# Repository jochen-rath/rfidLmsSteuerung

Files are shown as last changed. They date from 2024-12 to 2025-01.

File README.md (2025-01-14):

# Den Lyrion Media Server mit RFID Karten steuern

## Inhalt

* [Vorbemerkung](#vorbemerkung)
* [Aufbau](#aufbau)
* [Beispiel](#beispiel)
* [RFID Steuerung auf ESP32-Display](#rfidsteuerung)
* [RFID Karten Zuordnen](#rfidkartenzuordnen)
* [Installation restlicher Komponenten](#installationkomponenten)
* [ESP32-S3 Firmware selber erstellen](#esp32s3firmwareerstellen)

<a name="vorbemerkung"/>

## Vorbemerkung

Logitech hat vor lange Zeit einen kostenlosen Mediaserver bereit gestellt, mit dem man kostenlos seine Musik im ganzen Haus verteilen kann. Den Logitech (bzw. Lyrion) Media Server oder kurz LMS. Man braucht einen Rechner, der als Server arbeit und die Musik an verschiedene Clienten schickt. Diese können Rechner, Raspberry Pis, Handys oder seit kurzen ESP32 sein. Gerade die ESP32 sind eine sehr günstige alternative, die Musik zu empfangen.

Den LMS kann man gut mit Handy und Browser fernsteuern. Doch habe ich nicht immer mein Handy dabei und möchte auch gerne, dass meine Kinder selbständig Lieder und Hörbücher starten können. Für letzteres gibt es auch gute eigenständige Systeme, wie z.B. der TonUINO, aber gerade für ältere Kinder ist dies irgendwann nicht mehr zeitgemäß. Da ich selber schon länger den Lyrion Media Server (LMS) nutze und meinen Kinder den irgendwann auch in deren Zimmer einbauen wollte, entschied ich mich, mir eine RFID - Steuerung für diesen einzurichten.

<a name="aufbau"/>

## Aufbau

Aus folgenden vier Komponenten besteht ein komplettes System

1. Server mit einer laufenden LMS Instanz. ([Ich nutze Docker](https://hub.docker.com/r/lmscommunity/lyrionmusicserver))
2. Einen Clienten, der die Musik wiedergibt. ([Ich nutze squeezelite-esp32](https://github.com/sle118/squeezelite-esp32))
3. Die hier vorgestellte RFID-Steuerung.
4. Ein Pythonskript, welches den IDs der RFID-Karten einer Aktion zuordnen.

<a name="beispiel"/>

## Beispiel

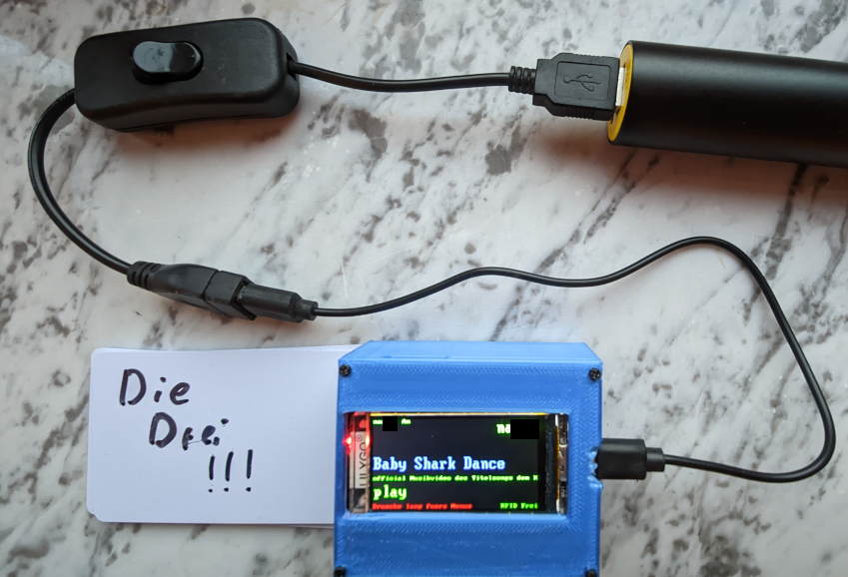
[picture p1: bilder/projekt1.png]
Beispiel 1

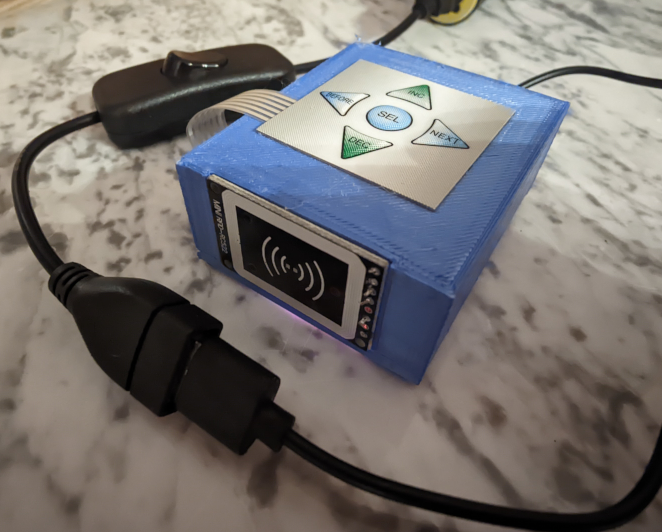
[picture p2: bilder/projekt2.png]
Beispiel 2


<a name="rfidsteuerung"/>

## RFID Steuerung auf ESP32-Display

### Komponenten
* T-Display-S3 ESP32 S3 with 1.9 inch ST7789 LCD Display
* MFRC-522 Mini RC522
* Key Button Membrane Switch 3 ([Color: 5key-matrix-keyboard](https://www.aliexpress.com/item/1005004528531101.html))
* USB Schalter
* USB Powerbank
* Gehäuse aus dem 3D-Druck

### Firmware flashen
```
pip install esptool
esptool.py --chip esp32s3 --port /dev/ttyACM0 erase_flash
esptool.py --chip esp32s3 --port /dev/ttyACM0 write_flash -z 0 esp32-S3_display_firmware.bin
```

### LMS-Steuerung aufs Display laden
Zur Übertragung des Skripts auf das ESP32 Display benutze ich Thonny. Wähle Run --> Select Interpreter --> Micropython (ESP32) und suche dann den richtigen Port. Speicher damit *squeezeplayerSteuerung.py* als *main.py* auf dem Display.

Wähle zuerst den Interpreter:

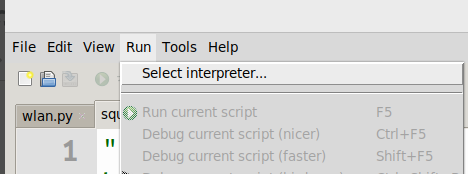
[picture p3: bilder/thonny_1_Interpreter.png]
Interpreter


Nimm MicroPython (ESP32) und den passenden Port:

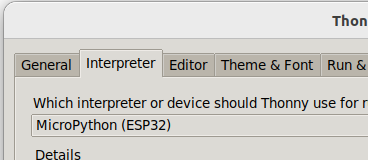
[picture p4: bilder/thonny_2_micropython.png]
Micropython


Drücke auf Save Copy und wähle das Micropython Device:

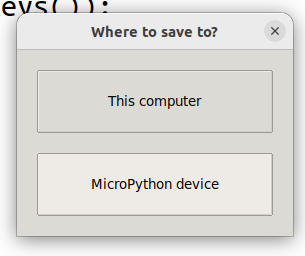
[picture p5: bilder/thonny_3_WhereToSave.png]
WhereToSave


### LMS-Steuerung anpassen
Rufe das Skript *paramter.py* in Thonny auf und passe folgende Angaben an:

* wlanname
* wlanpasswort
* squeezeclient
* lmsserverip
* rfidserverip

Speicher dann *parameter.py* auf dem Display.

### Komponenten Verbinden
**RFID**

| ESP32-S3 Display | MFRC-522 Mini RC522|
| --- | --- |
| V3.3 | V3.3 |
| GND | GND |
|  1 | MISO|
|  2 | MOSI |
|  3 | SCK|
| 10 | SDA|

**5 Button Switch**

| ESP32-S3 Display | 5 Button Switch|  Beschriftung |
| --- | --- | --- |
| GND | 1  | |
|  43 | 2  |SEL |
|  44 | 3  |DEC |
|  18 | 4  |INC |
| 17  | 5  |BEFORE |
| 21  | 6  |NEXT|

Ich habe den 5er Taster direkt an das ESP32 gelötet, um Platz zu sparen. Nicht gesteckt. Dazu habe ich den Stecker abgeschnitten und das die Enden der Kabel direkt an die Pins gelötet. Dadurch muss das Gehäuse nicht so hoch sein.

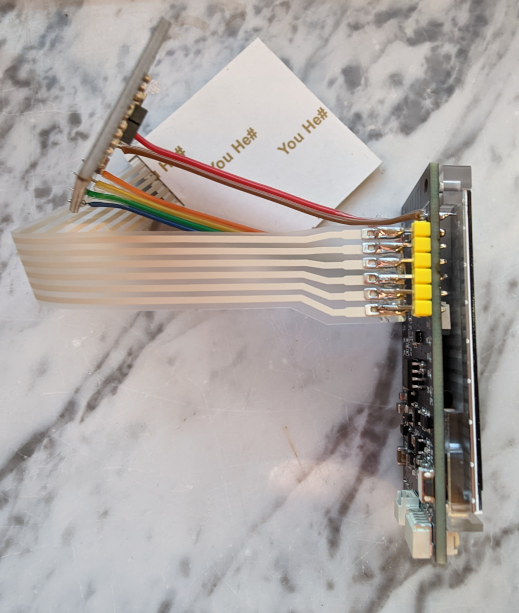
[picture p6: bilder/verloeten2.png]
verloeten 2
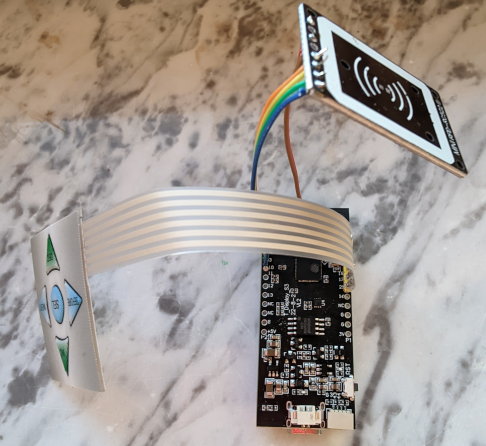
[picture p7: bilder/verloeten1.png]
verloeten 1
  

Da das Display die Schrauben verdeckt, klebe ich die Steuerung mit Heißkleber in das Gehäuse:

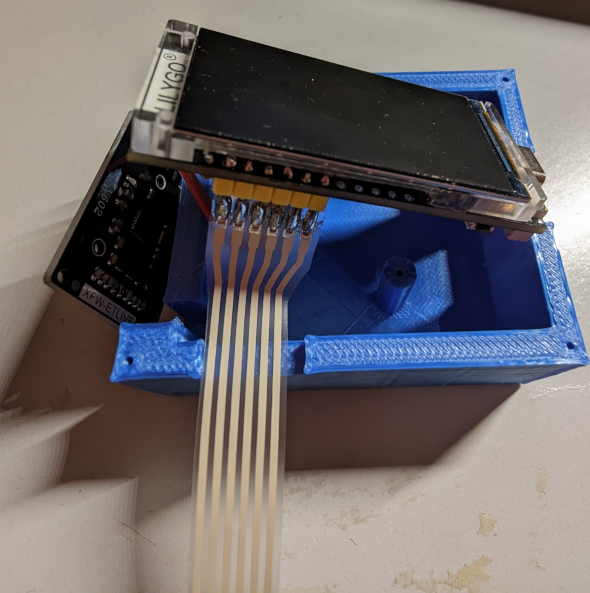
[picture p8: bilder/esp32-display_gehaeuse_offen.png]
Gehaeuse offen
 

<a name="rfidkartenzuordnen"/>

## RFID Karten Zuordnen

Die RFID Karten werden mit Hilfe eines Python Skripts verschiednenen Musikordnern, -dateien, -streams, Hörbüchern oder An- Ausschaltern zugeordnet.

1. Kopiere das Skript *httpServerGetPost.py* und die Datei *rfidKarten.csv* auf einen Server in den Ordner */home/pi/rfidLMS*
2. Kopiere als admin die Datei *rfidLMS.service* nach */lib/systemd/system*:  *sudo cp  rfidLMS.service /lib/systemd/system/*
3. Aktiviere das Skript als Service mit folgenden Befehlen:

```
sudo systemctl enable rfidLMS
sudo systemctl daemon-reload
sudo systemctl start rfidLMS
```
Möchtest du andere Pfade verwenden, passe die Ordner in den Skripten an. Ich habe die Datei *rfidKarten.csv* in einem Pfad gespeichert, auf dem ich per Samba mit meinem Handy zugriff habe. So kann ich einfach neue Karten in diese Datei einpflegen, indem ich mit dem NCF Reader meines Handy die Karten-ID auslese und diese einer Aktion zuordne.

<a name="installationkomponenten"/>

## Installation restlicher Komponenten

### LMS Server

Zur Docker-Installation [kopiere dir die Docker-Compose Datei](https://hub.docker.com/r/lmscommunity/lyrionmusicserver) auf deinen Server und starte den LMS Server mit 
```
docker-compose up -d
```
Richte den Server den eigenen Anforderungen entsprechend ein.

### squeezelite-esp32

#### Offiziele Clienten

Es gibt verschiedene Projekte, die direkt das Squeezelite-ESP32 unterstützen. Diese finden sich hier:

[Firmware for ESP Audio Dock](https://sonocotta.github.io/esp32-audio-dock/)

#### ESP32-S3

Aus Kostengründen nutze ich aber den ESP32-S3, welcher keine offiziele Unterstützung besitzt. Für den ESP32-S3 Clienten braucht man folgende Teile:

1. ESP32-S3 Development Board (z.B. von Aliexpress, auf 16MB achten: N16R8 - 8M psram, 16M flash)
2. DAC Module 1334 UDA1334A I2S DAC (z.B. von Aliexpress)
3. SONOFF Basic R2 (Zum An-Aus Schalten mitteils RFID-Karten)
4. USB Netzteil
5. USB Splitter, Eins auf Zwei (Nur ein Netzteil für Boxen und Esp32)
6. USB Boxen
7. 3.5mm Audio Aux Cable Anti-interference Ground Loop Noise Filter (Falls der Sound störgeräusche enthält. Dies kann bei mir vorkommen, wenn Boxen und ESP32-S3 am gleichen Netzteil hängen.)

#### ESP32-S3 Installation

**Softwareinstallation**

Für die 16 MB esp32-s3
```
pip install esptool
esptool.py --chip esp32s3 --port /dev/ttyACM0 erase_flash
esptool.py -p /dev/ttyACM0  -b 460800 --before default_reset --after hard_reset --chip esp32s3  write_flash --flash_mode dio --flash_size detect --flash_freq 80m 0x0 esp32s3_16MB_squeeze_bootloader.bin 0x8000 esp32s3_16MB_squeeze_partition-table.bin 0xd000 esp32s3_16MB_squeeze_ota_data_initial.bin 0x10000 esp32s3_16MB_squeeze_recovery.bin 0x150000 esp32s3_16MB_squeeze_squeezelite.bin

```

**ESP32-S3 mit DAC verbinden**

Verlöte folgende Punkte zwischen dem ESP und dem DAC

| ESP32-S3 | DAC 1334|
| --- | --- |
| V3.3 | V3.3 |
| GND | GND |
|  42 | WSEL |
|  41 | DIN |
|  40 | BCLK

Mache die Verbindung nicht zu kurz, sonst erzeugt der WLAN des esp32-S3 Störungen bei der Musikwiedergabe. 

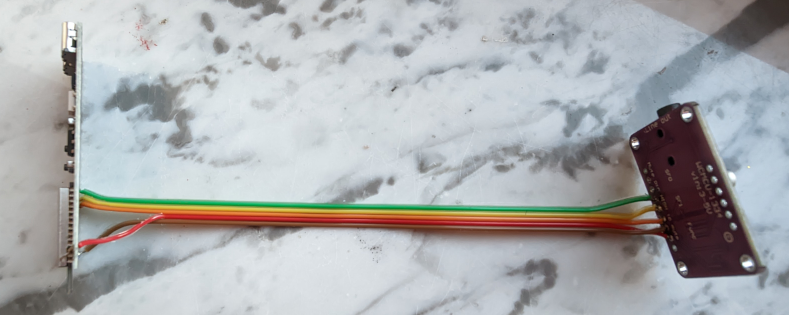
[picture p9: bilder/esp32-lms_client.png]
Verbindung


**ESP32-S3 Einrichten**

Verbinde dich mit dem ESP32-S3 mit dem Handy, WLAN squeezelite-esp32, Passwort squeezelite. Richte dein Wlan ein und merk dir die IP-Adresse, mit der sich der Squeezelite mit deinem Heimnetz verbindet. Rufe nach dem Neustart diese IP-Adresse auf.

Richte unter Audio den Playername und den LMS-Server ein:

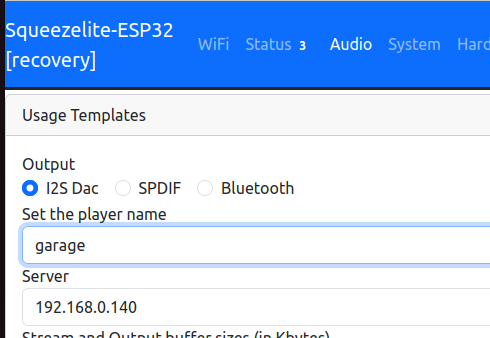
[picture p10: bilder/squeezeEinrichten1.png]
PlayerName


Richte unter Hardware den DAC entsprechend obiger Tabelle ein, bzw. deiner eigenen Verlötung:

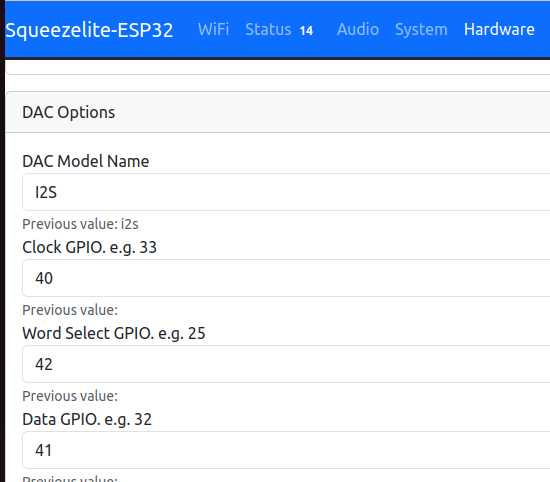
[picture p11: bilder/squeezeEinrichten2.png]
DAC


**Autoconnect**

Die hier genuzte Version des esp32-squeezelite Players kann sich nicht selber mit dem Server verbinden. [Hier wird beschrieben, welcher Schritt nochfehlt](https://github.com/sle118/squeezelite-esp32/issues/411#issuecomment-2104861151)

Es muss noch autoexec 1 im NVS-Editor eingefügt werden:

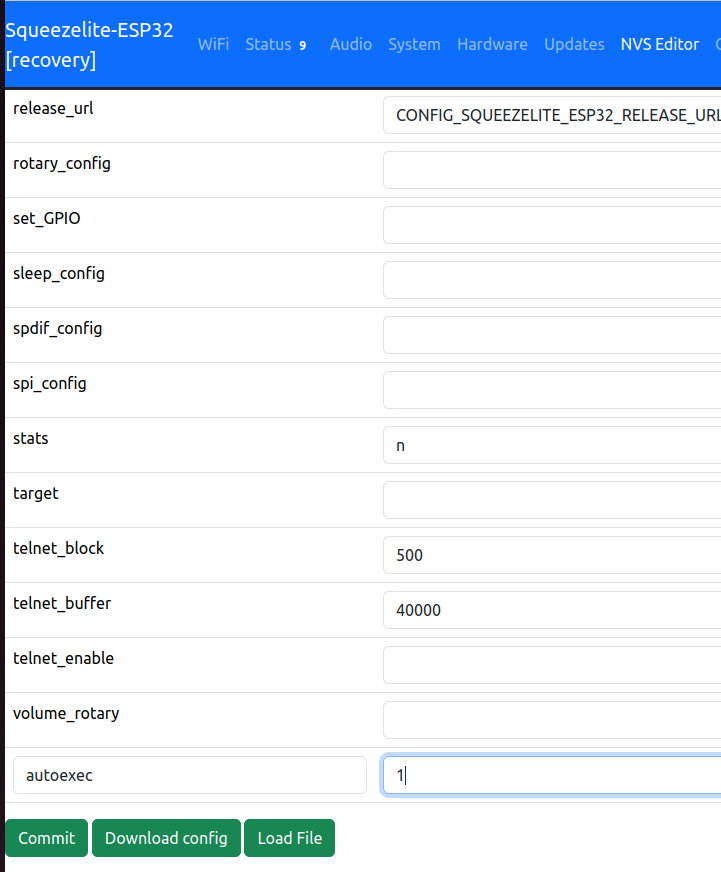
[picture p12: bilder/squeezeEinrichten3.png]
autoexec


Nach dem Neustart muss dies so aussehen:

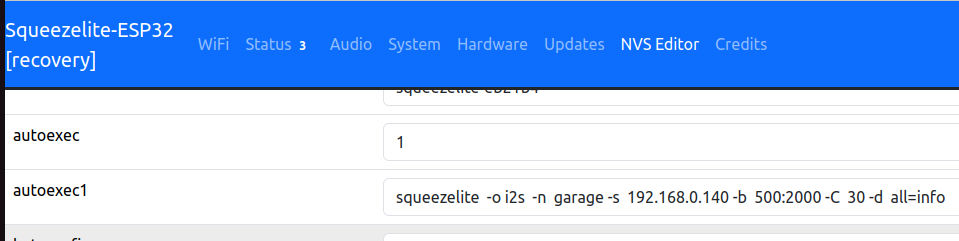
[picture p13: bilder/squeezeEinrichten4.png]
Ergebnis


### Sonoff Basic einrichten

Zum An und Auschalten der ESP32-S3 Clienten nutze ich den Sonoff Basic R2, welcher [mit einer Tasmota Firmaware geflasht wurde.](https://tasmota.github.io/docs/devices/Sonoff-Basic/)

**Sonoff Flashen**

Ablauf:

1. [Lade dir die Firmware herunter](https://ota.tasmota.com/tasmota/release/tasmota-DE.bin)
2. Öffne das Gehäuse
3. Löte 5 Pins an die richtige Stelle.
4. Verbinde die 5 Pins mit einem FT232RL USB-Serial Adapter, halte dabei den Reset-Knopf gedrückt.
5. Lösche den Speicher und flashe die Tasmota mit folgenden Befehlen:

```
esptool.py --port /dev/ttyUSB0 erase_flash
esptool.py --port /dev/ttyUSB0 write_flash -fs 1MB -fm dout 0x0 tasmota-DE.bin
```
[Hier ist eine ausführliche Anleitung mit Bildern.](https://medium.com/@jordanrounds/sonoff-basic-r2-tasmota-aa6f9d4e033f)

<a name="esp32s3firmwareerstellen"/>

## ESP32-S3 Firmware selber erstellen

Sollte dein ESP32-S3 nicht zu den hier vorgestellten Konfigurationen passen, erstelle deine eigene Firmware mit folgenden Befehlen:

```
mkdir ~/esp
cd ~/esp
git clone -b v4.4.4 --recursive https://github.com/espressif/esp-idf.git esp-idf-v4.4
~/esp/esp-idf-v4.4/install.sh
. ~/esp/esp-idf-v4.4/export.sh
git clone --recursive https://github.com/sle118/squeezelite-esp32.git
cd squeezelite-esp32
cp build-scripts/I2S-4MFlash-sdkconfig.defaults sdkconfig.defaults

```

Änder nun in der Datei sdkconfig.defaults die *CONFIG_IDF_TARGET="esp32"* zu *CONFIG_IDF_TARGET="esp32s3"*

**ESP32-S3 Konfigurieren**

Passe mit dem Befehl *idf.py menuconfig* folgende Einstellungen an. Da der ESP32-S3 kein Bluetooth hat, muss dies deaktiviert werden.

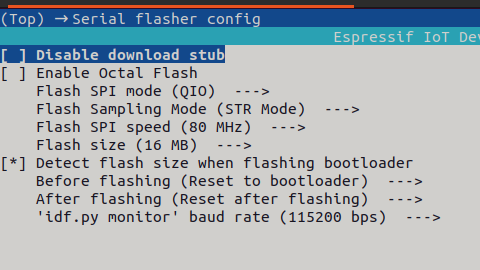
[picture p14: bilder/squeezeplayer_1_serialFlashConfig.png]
serialFlashConfig

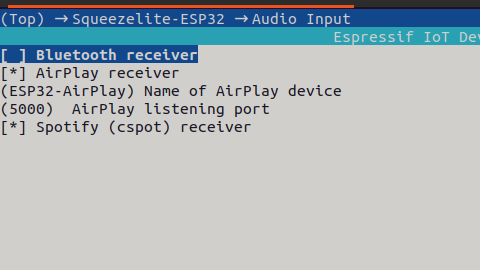
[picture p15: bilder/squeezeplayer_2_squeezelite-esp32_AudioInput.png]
esp32_AudioInput

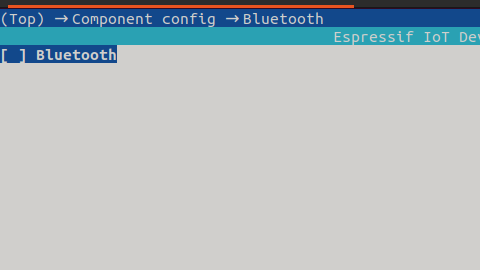
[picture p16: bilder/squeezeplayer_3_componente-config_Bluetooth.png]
config_Bluetooth

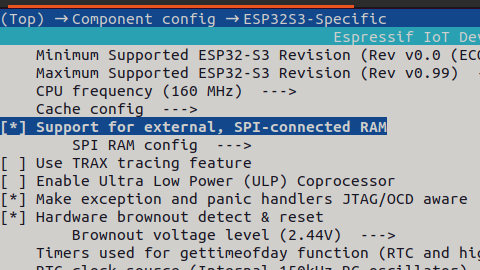
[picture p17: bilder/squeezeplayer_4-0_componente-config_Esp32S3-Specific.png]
config_Esp32S3-Specific

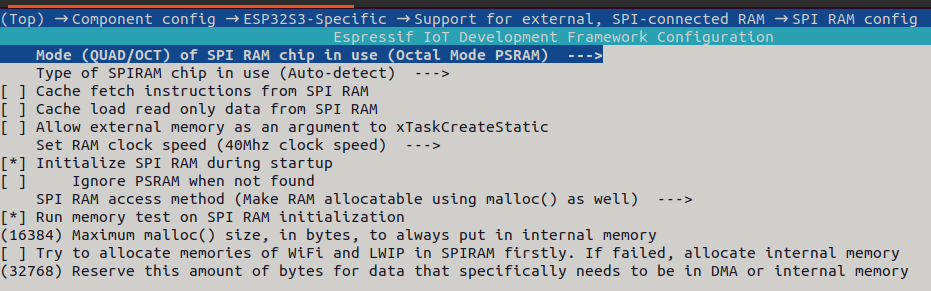
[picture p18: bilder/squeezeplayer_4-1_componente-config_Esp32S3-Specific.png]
config_Esp32S3-Specific

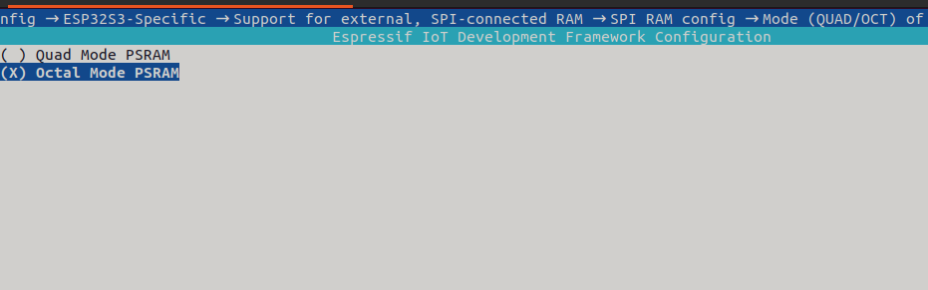
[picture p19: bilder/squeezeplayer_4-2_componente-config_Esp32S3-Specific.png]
config_Esp32S3-Specific

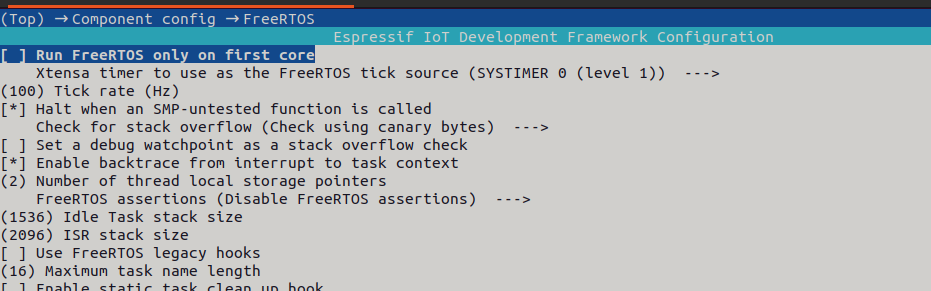
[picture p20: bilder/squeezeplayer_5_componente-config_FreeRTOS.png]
config_FreeRTOS


Führe dann folgende Befehle aus:

```
idf.py build
idf.py flash
```

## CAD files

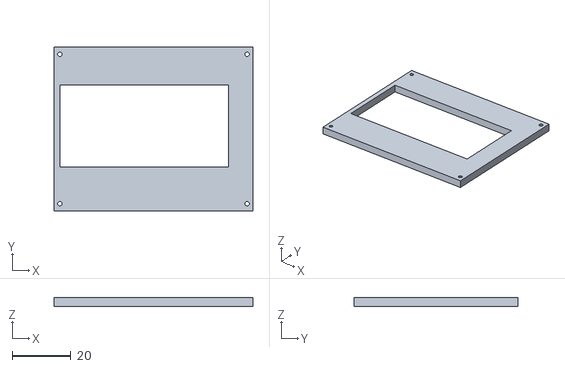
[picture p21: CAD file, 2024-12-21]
gehaeuse/esp32-Display-GehaeuseKnopKleber-Deckel.stl
67.9 x 56.0 x 3.00

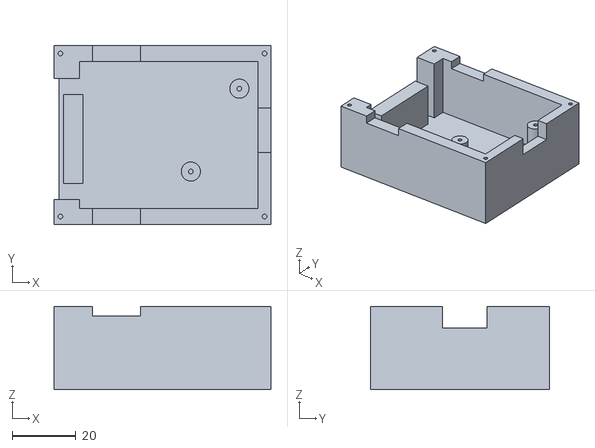
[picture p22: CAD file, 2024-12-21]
gehaeuse/esp32-Display-GehaeuseKnopKleber-RFID_Gehaeuse.stl
67.9 x 56.0 x 26.0

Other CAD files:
gehaeuse/esp32-Display-GehaeuseKnopKleber.blend

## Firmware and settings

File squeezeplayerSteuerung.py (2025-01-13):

"""
hello.py

    Writes "Hello!" in random colors at random locations on the display.
"""
import urequests
import ujson
from switch import Switch

import wlan
import parameter
import machine
import utime
import random
import time
import uping
import uasyncio as asyncio
import vga2_bold_16x32 as big
#import romans as big
import vga2_bold_16x16 as medium
#import italiccs as medium
import vga2_8x8 as small
#import romanp as small
import tft_config
import tft_buttons
import s3lcd

from machine import Pin, SPI
from mfrc522 import MFRC522

wlan.wlan_connect(ssid=parameter.werte('ssid'),password=parameter.werte('password'))

sck = Pin(3, Pin.OUT)
mosi = Pin(2, Pin.OUT)
miso = Pin(1, Pin.OUT)
spi = SPI(baudrate=100000, polarity=0, phase=0, sck=sck, mosi=mosi, miso=miso)

sda = Pin(10, Pin.OUT)

statusFailed=False
tft = tft_config.config(tft_config.WIDE)
tft.init()
BACKGROUND=s3lcd.BLACK
GREEN=s3lcd.GREEN
RED=s3lcd.RED
BLUE=s3lcd.BLUE

incSwitch = Switch(18)
decSwitch = Switch(44)
befSwitch = Switch(17)
nexSwitch = Switch(21)
selSwitch = Switch(43)


def decSwitch_changed(change):
    if change == decSwitch.SW_RELEASE:
        display.decIncKnopf(-1)
def incSwitch_changed(change):
    if change == incSwitch.SW_RELEASE:
        display.decIncKnopf(1)
def befSwitch_changed(change):
    if change == befSwitch.SW_RELEASE:
        display.befNexKnopf(-1)
def nexSwitch_changed(change):
    if change == nexSwitch.SW_RELEASE:
        display.befNexKnopf(1)
def selSwitch_changed(change):
    global zeitVor
    global display
    if change == selSwitch.SW_RELEASE:
        zeitNach=utime.ticks_ms()
        if zeitNach-zeitVor > 500:
            display.selGedrueckt('lang')
        elif zeitNach-zeitVor > 50:
            display.selGedrueckt('kurz')
    else:
        zeitVor= utime.ticks_ms()

incSwitch.add_handler(incSwitch_changed)
decSwitch.add_handler(decSwitch_changed)
befSwitch.add_handler(befSwitch_changed)
nexSwitch.add_handler(nexSwitch_changed)
selSwitch.add_handler(selSwitch_changed)


zeitVor=0


class displayInhalt:
    hauptmenu={'Volumen':'self.volumenDisplay()','Wiedergabeliste':'self.stelleMenuDar(self.wiedergabe,2)','Playerauswahl':'self.stelleMenuDar(self.playersMenue,2)','Zurueck':'self.ebeneNull()'}
    wiedergabe={'Sport':'self.playVari(["playlist","play","/home/share/PlayLists/Sport.m3u"]); self.ebeneNull();','Zufall':'self.playVari(["randomplay","tracks"]); self.ebeneNull();','FFN':'self.playUrl("http://player.ffn.de/ffnstream.mp3"); self.ebeneNull()','Zurueck':'self.stelleMenuDar(self.hauptmenu,1)'}
    playersMenue={}
    menuEbene=0
    index=0
    naechstesLied=''
    vorherigesLied=''
    textUntenEbeneNull='Druecke lang fuers Menue'
    textUntenMenue='Druecke lang fuer zurueck'
    aktuellesMenu=None
    aktIndex=0
    anzLieder=0
    sonoff=f'{parameter.werte("player")}{parameter.werte("sonoff")}'
    playercount=0
    untenRechts="RFID Frei"
    obenLinks=""
    def __init__(self, player=parameter.werte('player'),url=parameter.werte('server')):
        self.url=url
        self.player=player
        self.playerStart=player
        self.getPlayers()
        self.updatePlayer()
        self.ebeneNull()
    def updatePlayer(self,):
        self.getPlayers()
        if self.player:
            statjson=ujson.dumps({"id":1,"method":"slim.request","params":[self.players[self.player],["status","-",1,"tags:al"]]})
            res=self.requestsAbfrage(data=statjson,ort='updatePlayer')
            if res==-1:
                global statusFailed
                statusFailed=True
                return
            jsondata=ujson.loads(res.text)
            self.lied=jsondata['result']['playlist_loop'][0]['title'] if 'playlist_loop' in jsondata['result'].keys() else ''
            self.volumen=jsondata['result']['mixer volume']
            self.playStatus=jsondata['result']['mode']
            self.status=self.playStatus
            self.getAktuelleLieder()
        else:
            self.lied=''
            self.volumen=0
            self.playStatus='Nichts'
            self.player=self.playerStart
            self.getPlayers()
#        print(jsondata['result'])
    def getPlayers(self,):
#        try:
        serverstatus=ujson.dumps({"id":1,"method":"slim.request","params":["",["serverstatus", 0, 999]]})
        res=self.requestsAbfrage(data=serverstatus,ort='getPlayers')
        if res==-1:
            self.player = None
            return
        jsondata=ujson.loads(res.text)
        self.playercount=jsondata['result']['player count']
        self.players={}
        self.playersMenue={}
        if self.playercount>0:
            for i in range(self.playercount):
                playername=jsondata['result']['players_loop'][i]['name']
                self.players[playername]=jsondata['result']['players_loop'][i]['playerid']
                self.playersMenue[playername]=f'self.player="{playername}"; self.ebeneNull()'
        self.player = self.player if self.player in self.players.keys() else None
#        except:
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

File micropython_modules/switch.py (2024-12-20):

import machine
import utime as time
from machine import Pin
import micropython

class Switch:
    SW_PRESS = 4
    SW_RELEASE = 8

    def __init__(self,sw):
        self.sw_pin = Pin(sw, Pin.IN, Pin.PULL_UP)
        self.sw_pin.irq(handler=self.switch_detect, trigger=Pin.IRQ_FALLING | Pin.IRQ_RISING )
        self.handlers = []
        self.last_button_status = self.sw_pin.value()

    def switch_detect(self,pin):
        if self.last_button_status == self.sw_pin.value():
            return
        self.last_button_status = self.sw_pin.value()
        if self.sw_pin.value():
            micropython.schedule(self.call_handlers, Switch.SW_RELEASE)
        else:
            micropython.schedule(self.call_handlers, Switch.SW_PRESS)

    def add_handler(self, handler):
        self.handlers.append(handler)

    def call_handlers(self, type):
        for handler in self.handlers:
            handler(type)

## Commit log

2024-12-21 Firmware - Parameter
    [esp32-Display-GehaeuseKnopKleber-Deckel.stl, esp32-Display-GehaeuseKnopKleber-RFID_Gehaeuse.stl, esp32-Display-GehaeuseKnopKleber.blend]
2024-12-28 Firmware ESP32-S3
    [rfidKarten.csv]
